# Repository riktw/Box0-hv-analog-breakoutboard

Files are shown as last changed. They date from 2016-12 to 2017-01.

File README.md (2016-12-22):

A breakout board for the Box0 so the Box0 is able to handle higher analog voltages
With this it can handle -33 to +33V on the input and output -33V to +33V as well.

The hardware is simple, 2 switching power supplies to boost the 5V in to +-33V, possible +-35V
After that 2 +-50V 50mA output capable opamps with a gain of 10 and a divide by 10 voltage devider so the analog inputs can handle +-33V as well

An USB port is added to supply the board with 5V as the 5V pin of the Box0 is unable to deliver enough current.
A small example:

10mA at 35V means that, at 100% efficiency, 70mA is needed at 5V, in practise this figure is closer to 90mA
With 2 opamps being capable of delivering 50mA a total of 100mA at 35V is required, meaning 900mA at 5V as input.

Current limit is implemented by using a 1A polyfuse, minimal but better then nothing. 

License: CC-SA-BY 4.0

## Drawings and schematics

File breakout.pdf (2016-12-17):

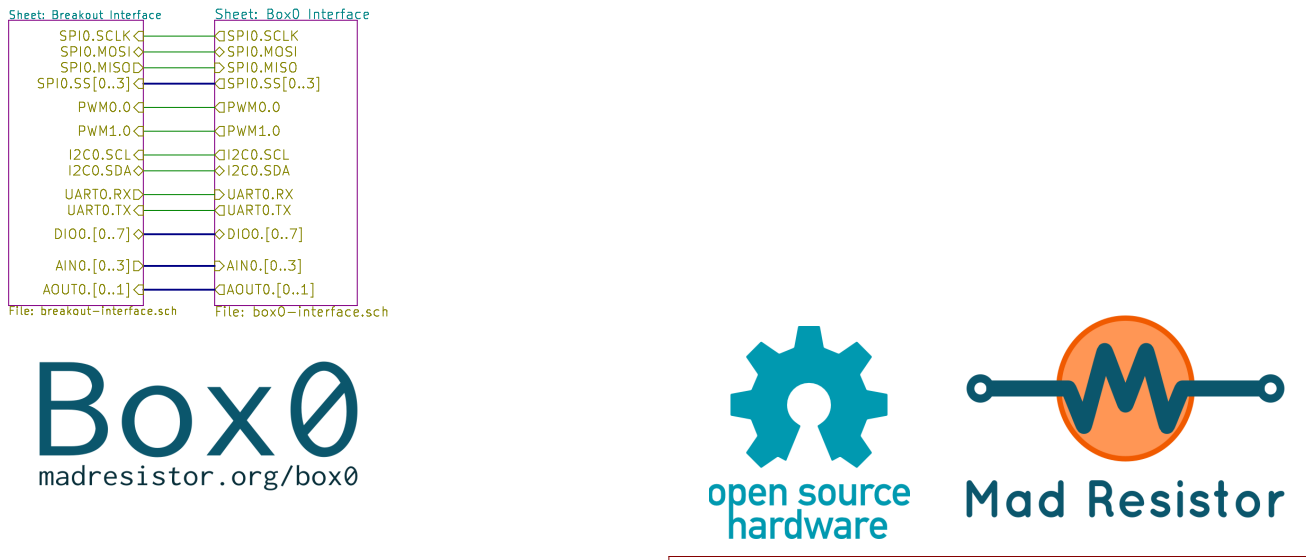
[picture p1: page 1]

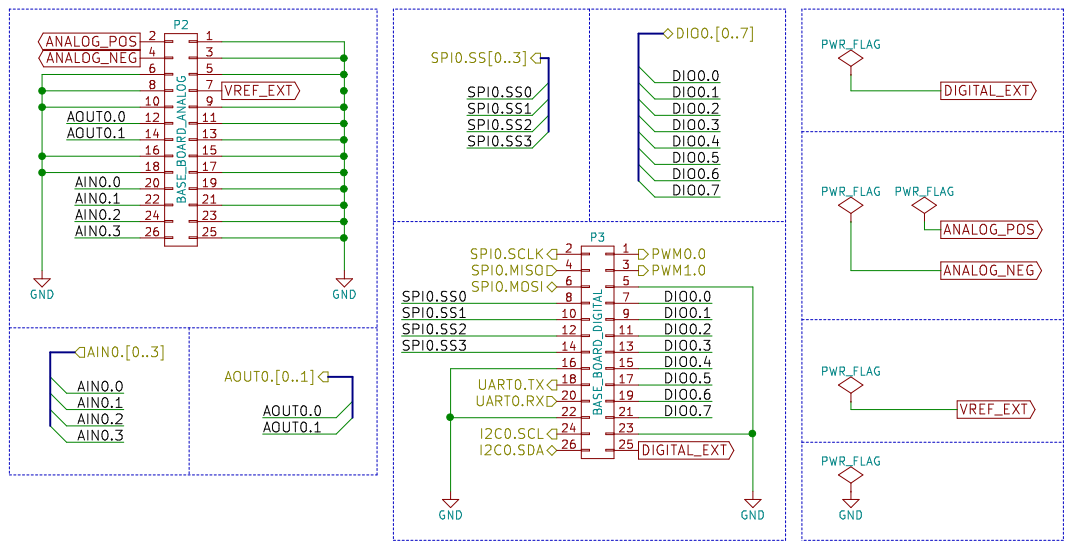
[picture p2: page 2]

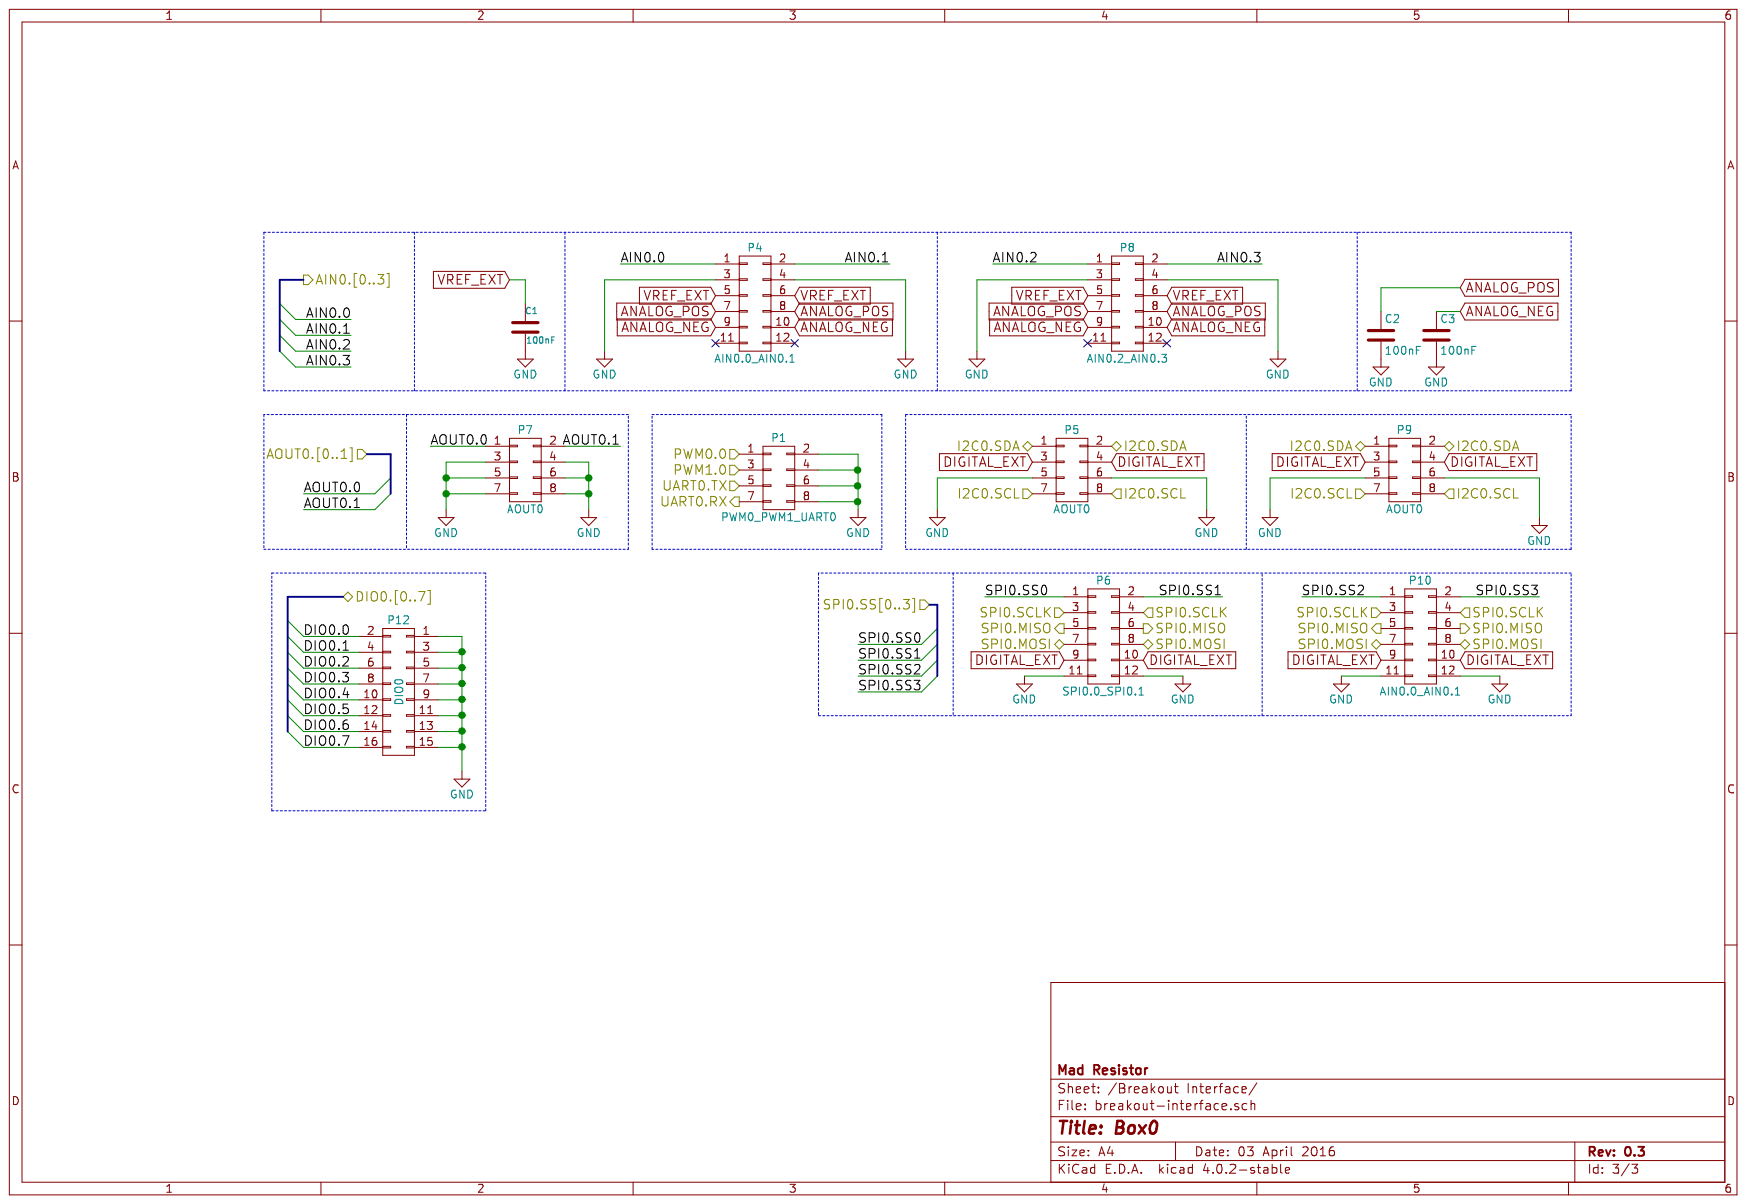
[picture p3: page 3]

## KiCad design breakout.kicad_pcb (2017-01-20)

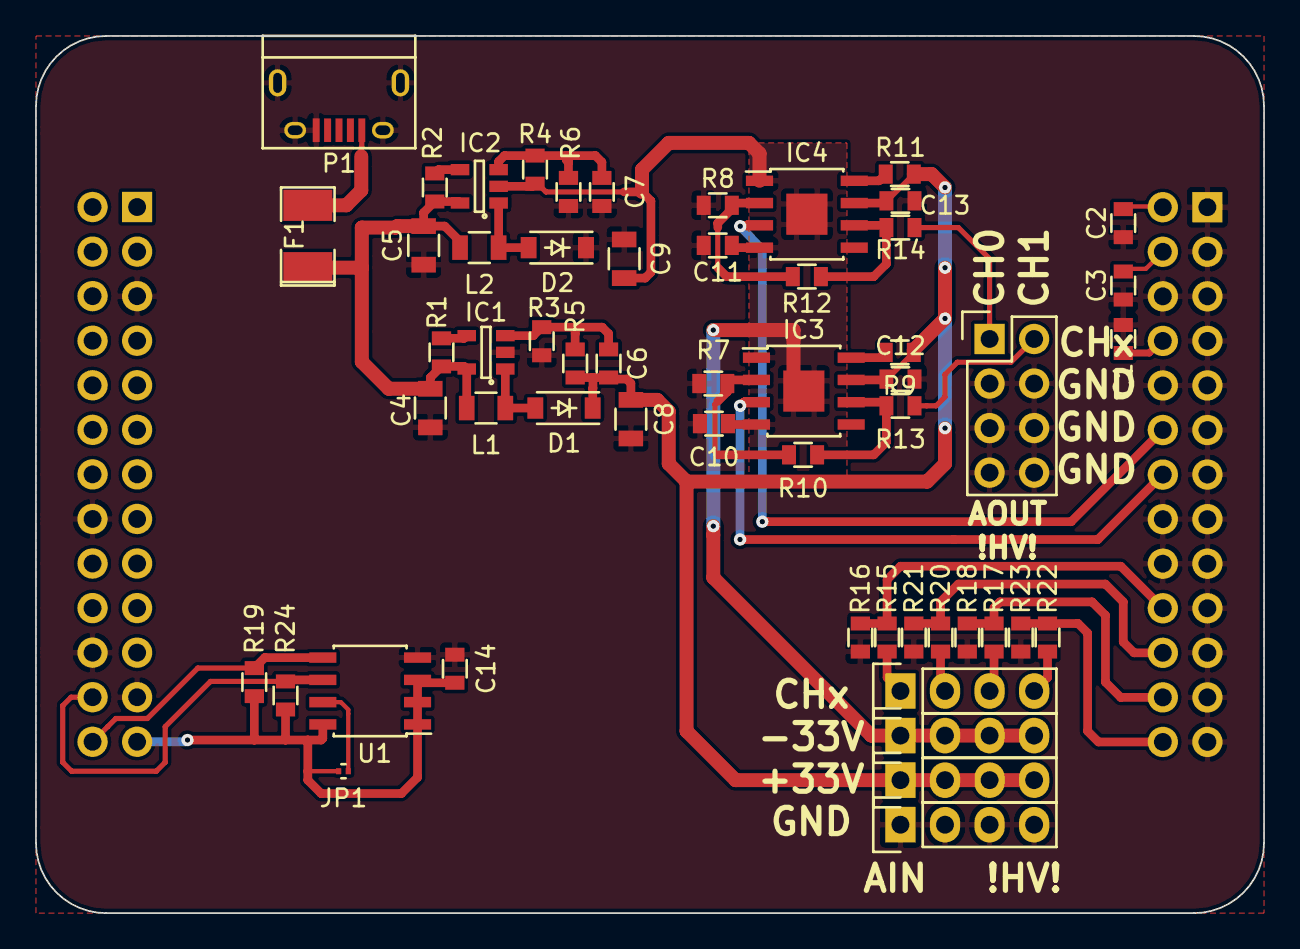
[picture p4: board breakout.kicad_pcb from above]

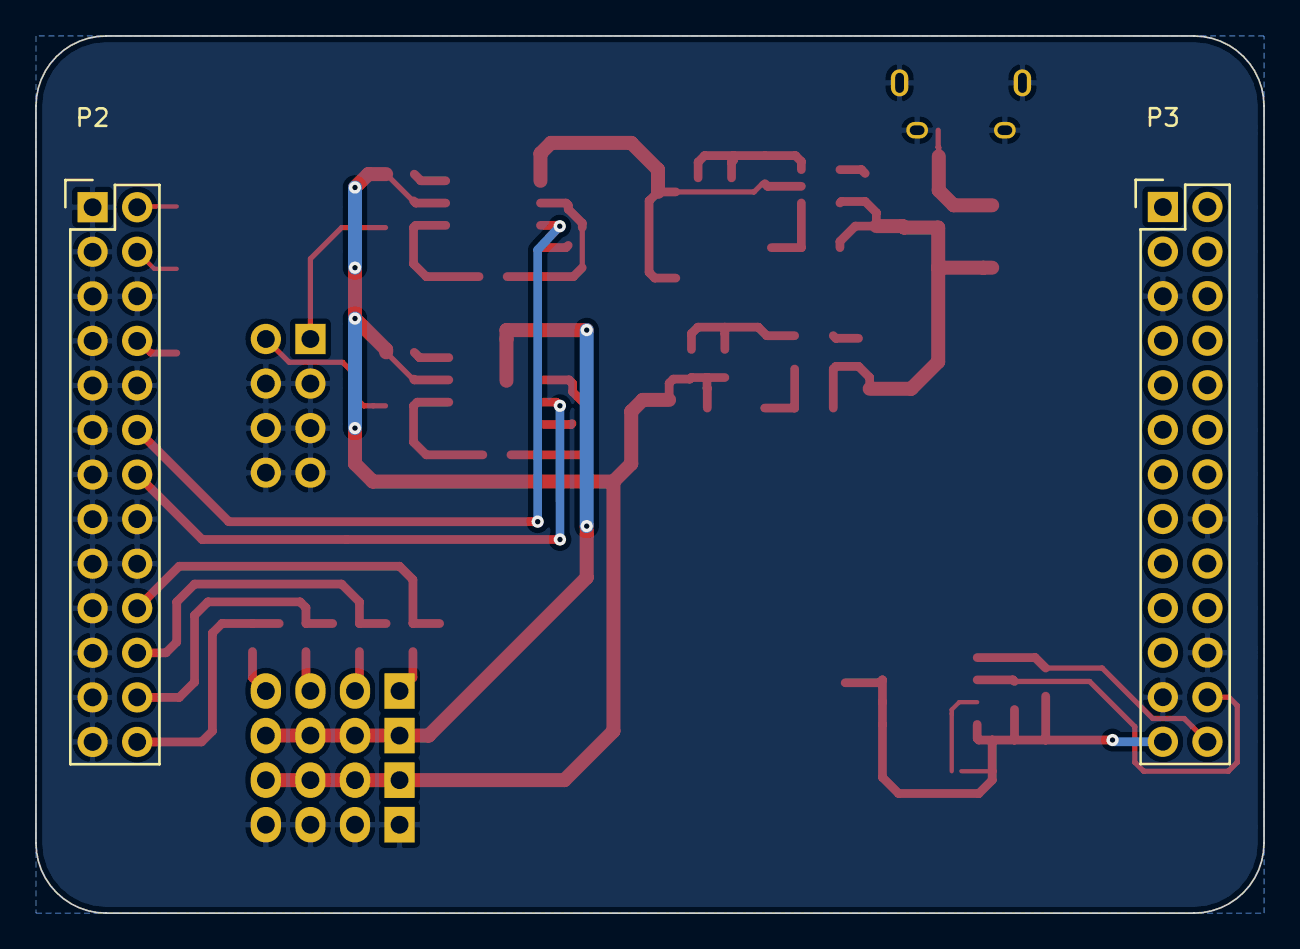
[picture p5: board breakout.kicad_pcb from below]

Board: 2 copper layers, 70.0 x 50.0 mm, 57 parts (2 on the bottom side), 36 nets.

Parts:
C1, C2, C3: 100nF; 0603
C4, C5: 4.7u; 0805
C6, C7: 82p; 0603
C8, C9: 10u; 0805
C10, C11, C12, C13, C14: 100n; 0603
D1, D2: MBR0540; SOD-123
F1: F_Small; SMD-1210_Pol
IC1, IC2: LM2733; SOT-23-5
IC3, IC4: OPA454; SOIC-8-3.9*4.9mm_HP_to_P4
JP1: Jumper_NO_Small; C_0201
L1, L2: 10u; 0805
P1: USB_OTG; USB_Micro-B
P2: BASE_BOARD_ANALOG; Pin_Header_Straight_2x13
P3: BASE_BOARD_DIGITAL; Pin_Header_Straight_2x13
P4: CONN_02X04; Pin_Header_Straight_2x04
P5, P6, P7, P8: CONN_01X04; Pin_Header_Straight_1x04
R1, R2: 47K; 0603
R3, R4: 12K; 0603
R5, R6: 309K; 0603
R7, R8, R16, R18, R21, R23: 10K; 0603
R9, R11: 1M; 0603
R10, R12, R15, R17, R20, R22: 91K; 0603
R13, R14: 10R; 0603
R19, R24: 4.7K; 0603
U1: 24C16; SOIC-8_3.9x4.9mm_Pitch1.27mm

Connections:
5V: C4.1, C5.1, F1.1, IC1.5, IC2.5, L1.2, L2.2, R1.1, R2.1
+33V: C6.2, C8.1, C12.1, C13.1, D1.1, IC3.7, IC4.7, P6.1, P6.2, P6.3, P6.4, R5.2, R9.1, R11.1
-33V: C9.2, C10.1, C11.1, IC2.2, IC3.1, IC3.4, IC4.1, IC4.4, P7.1, P7.2, P7.3, P7.4, R4.2
/Box0 Interface/AIN0.0: P2.20, R15.1, R16.2
/Box0 Interface/AIN0.1: P2.22, R20.1, R21.2
/Box0 Interface/AIN0.2: P2.24, R17.1, R18.2
/Box0 Interface/AIN0.3: P2.26, R22.1, R23.2
/Box0 Interface/AOUT0.0: IC4.3, P2.12
/Box0 Interface/AOUT0.1: IC3.3, P2.14
/Box0 Interface/I2C0.SCL: P3.24, R24.2, U1.6
/Box0 Interface/I2C0.SDA: P3.26, R19.2, U1.5
ANALOG_NEG: C3.1, P2.4
ANALOG_POS: C2.1, P2.2
DIGITAL_EXT: C14.1, JP1.1, P3.25, R19.1, R24.1, U1.1, U1.2, U1.3, U1.8
GND: C1.2, C2.2, C3.2, C4.2, C5.2, C7.2, C8.2, C9.1, C10.2, C11.2, C12.2, C13.2, C14.2, D2.1, IC1.2, P1.5, P1.6, P2.1, P2.3, P2.5, P2.6, P2.7, P2.9, P2.10, P2.11, P2.13, P2.15, P2.16, P2.17, P2.18, P2.19, P2.21, P2.23, P2.25, P3.5, P3.16, P3.22, P3.23, P4.3, P4.4, P4.5, P4.6, P4.7, P4.8, P5.1, P5.2, P5.3, P5.4, R3.2, R6.2, R7.1, R8.1, R16.1, R18.1, R21.1, R23.1, U1.4
unnamed: C6.1, IC1.3, R3.1, R5.1
unnamed: C7.1, IC2.3, R4.1, R6.1
unnamed: D1.2, IC1.1, L1.1
unnamed: D2.2, IC2.1, L2.1
unnamed: F1.2, P1.1
unnamed: IC1.4, R1.2
unnamed: IC2.4, R2.2
unnamed: IC3.2, R7.2, R10.2
unnamed: IC3.6, R10.1, R13.2
unnamed: IC3.8, R9.2
unnamed: IC4.2, R8.2, R12.2
unnamed: IC4.6, R12.1, R14.2
unnamed: IC4.8, R11.2
unnamed: JP1.2, U1.7
unnamed: P4.1, R14.1
unnamed: P4.2, R13.1
unnamed: P8.1, R15.2
unnamed: P8.2, R20.2
unnamed: P8.3, R17.2
unnamed: P8.4, R22.2
VREF_EXT: C1.1, P2.8

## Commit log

2016-12-17 First commit, empty breakout board
    [box0-interface.sch, breakout-interface.sch, breakout.kicad_pcb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]
2016-12-18 Schematic nearly done
    [box0-interface.sch, breakout-interface.sch, breakout.kicad_pcb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]
2016-12-18 Started on PCB
    [breakout-interface.sch, breakout.kicad_pcb, breakout.sch]
2016-12-19 PCB almost done
    [breakout.kicad_pcb]
2016-12-22 Finished PCB
    [breakout.kicad_pcb]
2017-01-20 fixed the wrongly connected VREF
    [box0-interface.sch, breakout-interface.sch, breakout.kicad_pcb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]
